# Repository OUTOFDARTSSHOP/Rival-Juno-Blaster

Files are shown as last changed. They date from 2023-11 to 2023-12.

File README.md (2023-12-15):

# Juno

Juno is the successor to Jupiter with increased FPS, improved features, and open source nature.
This blaster contains the new OOD Photons and custom-made Rival wheels that fit standard shell profiles.

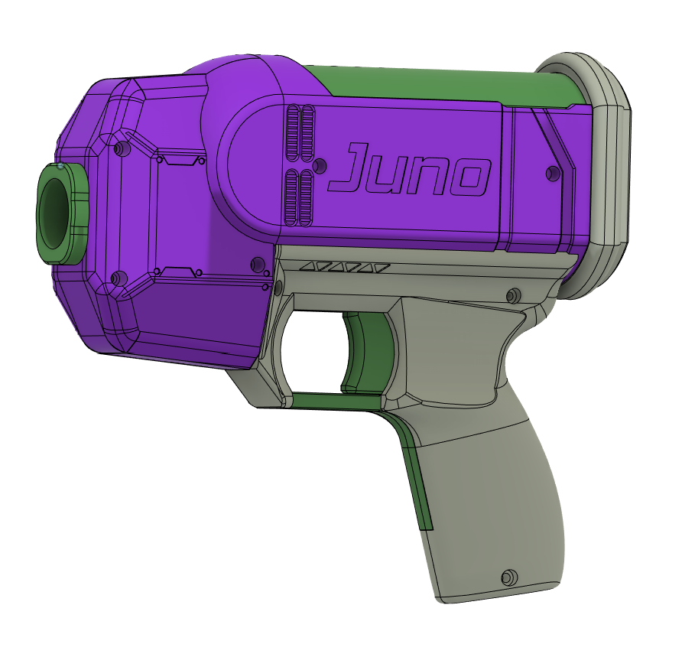
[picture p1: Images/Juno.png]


<details>
<summary> Changelog </summary>

- Changelog: 12-04-2023: v5.1 parts updated.
  -   N20 casing increased layers
  -   Cage shifted to accommodate the n20 case changes
  -   The chamfer on the pusher wheel is reduced to prevent slipping too far onto the shaft
  -   Added more plastic to the inner handle so the parts aren't just held by the pegs
- Changelog: 12-07-2023: v5.2 handle updates. 
  - Trigger trimmed in the right and left direction to help with sticking
  - A small chamfer was added near the trigger opening so seams didn't cause sticking.
- Changelog: 12-14-2023: v5.3 alternatives and clear instructions
  - Cage updated to include instructions on polarity and direction of motors
  - Add 2 more pusher wheel for looser fit
  - Update manual based on issue 1 and how the nozzle works. 

</details>

## Licensing

If you want to print and sell this item, please contact outofdarts@gmail.com.

<br />This work is licensed under a <a rel="license" href="http://creativecommons.org/licenses/by-nc-sa/4.0/">Creative Commons Attribution-NonCommercial-ShareAlike 4.0 International License</a>.

## Description

* Files can be found in two ways. The major file version can be found zipped together here. The latest release and any beta files can be on this GitHub.

* If you bought the hardware kit, it comes with two versions. The standard hardware contains all hardware for Juno and extra hardware for the Picatinny rails. Holdster Hardware replaces the M3 brass inserts with M5 and holdster magnets. Though not pictured, the installation process is the same. Only the Mag-Battery file needs to be changed.

* The battery is not included with the hardware kit. Most OOD batteries will fit in the large battery tray.

## Reviews

* Waiting for them to come in

### Hardware notes:

Hardware listing:
3D Printed + Hardware listing:
Fully assembled listing:

## Assembly

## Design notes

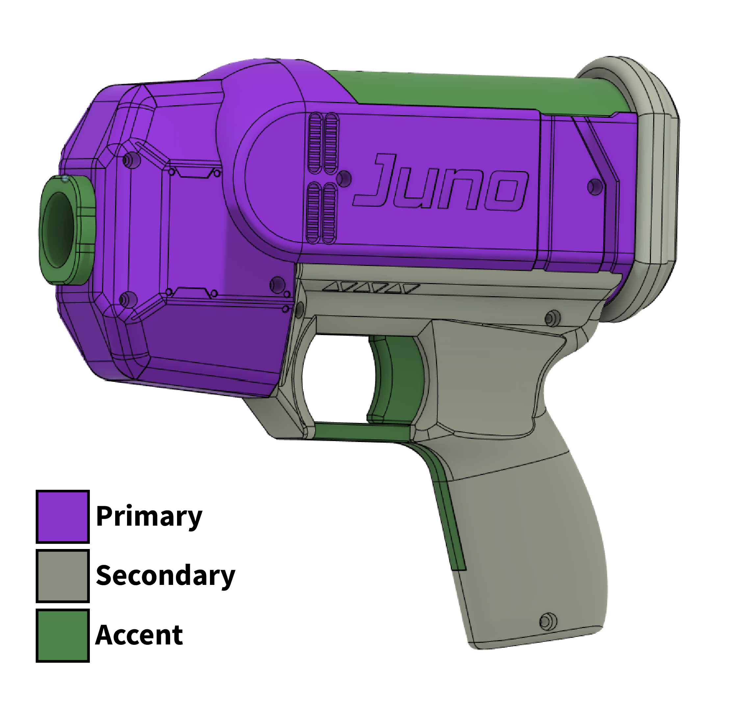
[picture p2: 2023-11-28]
Images/Juno-Colored.png

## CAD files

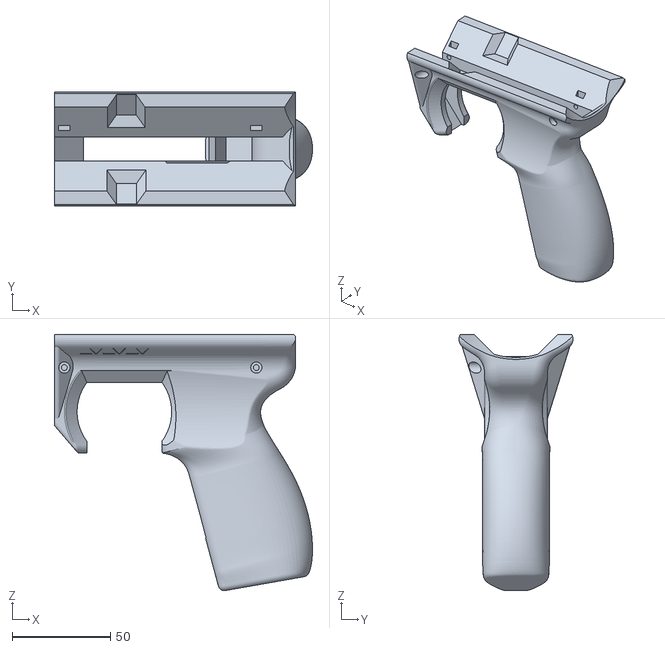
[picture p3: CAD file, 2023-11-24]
Juno v5/Archieve/Juno-HandleOuter_V5.stl
131.0 x 57.9 x 130.2

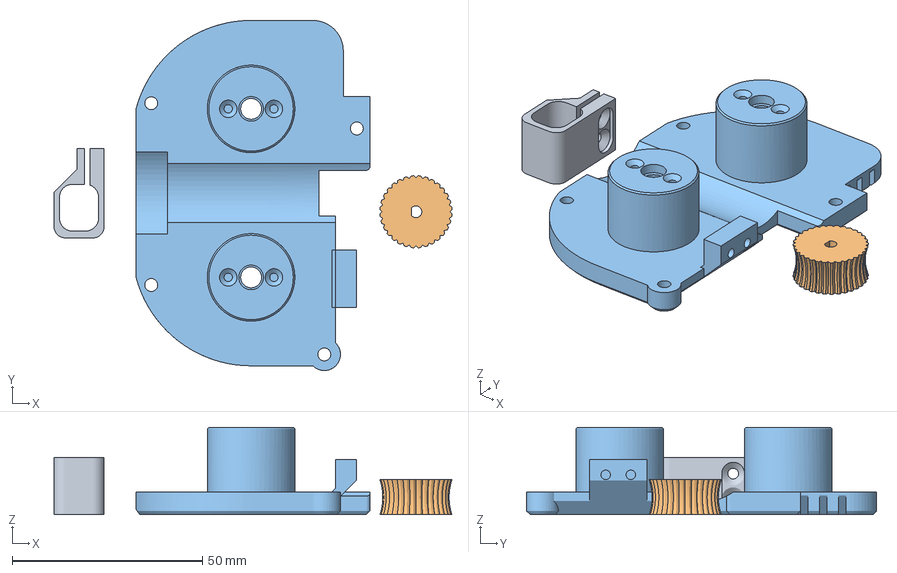
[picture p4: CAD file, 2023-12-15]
Juno v5/Juno-Misc_V5.3.3mf
104.6 x 92.0 x 23.0 mm
Juno-Pusher Casing_V5.1.stl
Juno-Pusher_V5.1.stl
Juno-Cage_V5.2.stl

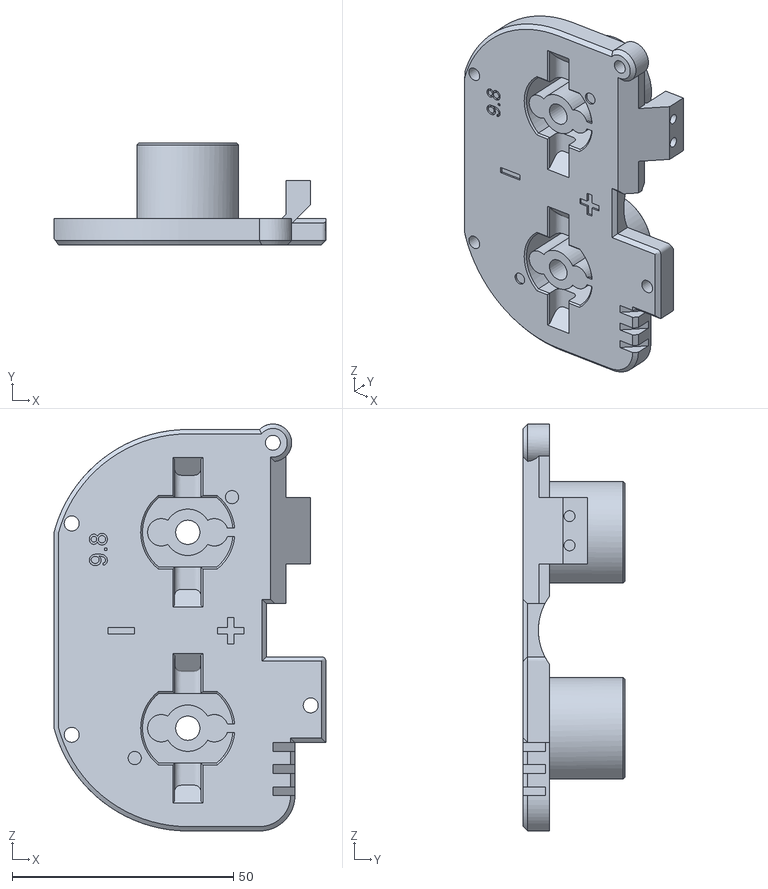
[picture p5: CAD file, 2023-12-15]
Juno v5/STLs/Front/Juno-Cage_V5.3.stl
61.5 x 23.0 x 92.0

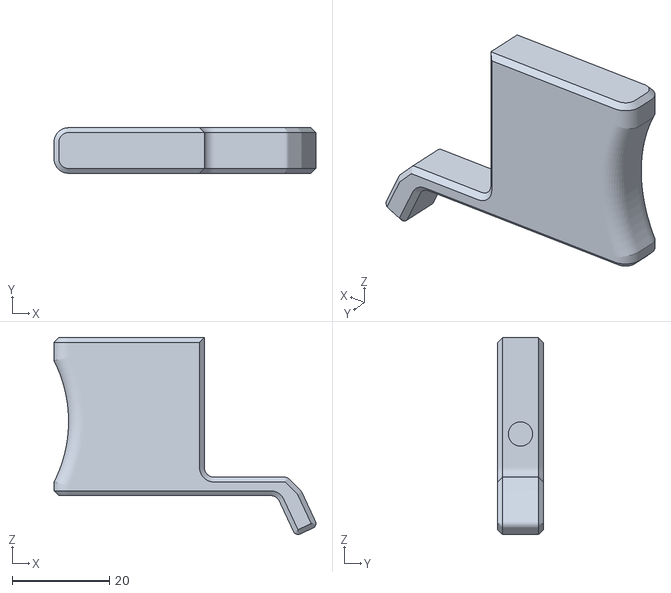
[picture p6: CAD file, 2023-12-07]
Juno v5/STLs/Handle/Juno-Trigger_V5.2.stl
54.0 x 9.40 x 40.6

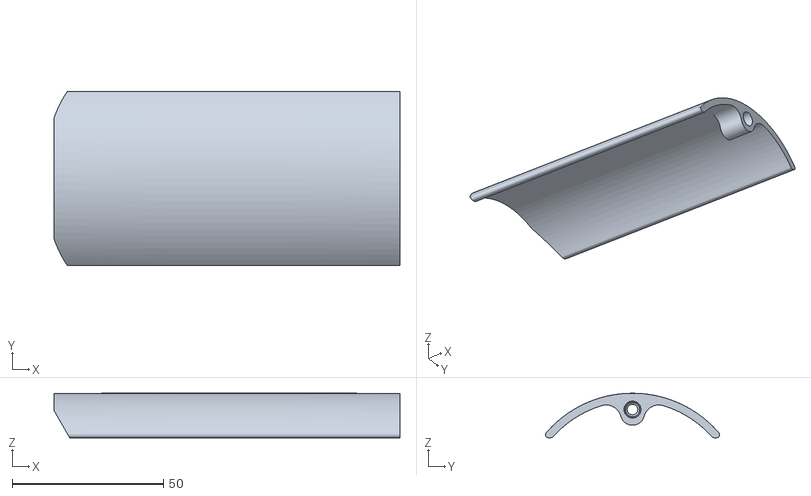
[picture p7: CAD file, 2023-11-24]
Juno v5/STLs/Mag-Battery/Juno-Cover_V5.stl
114.4 x 57.6 x 14.7

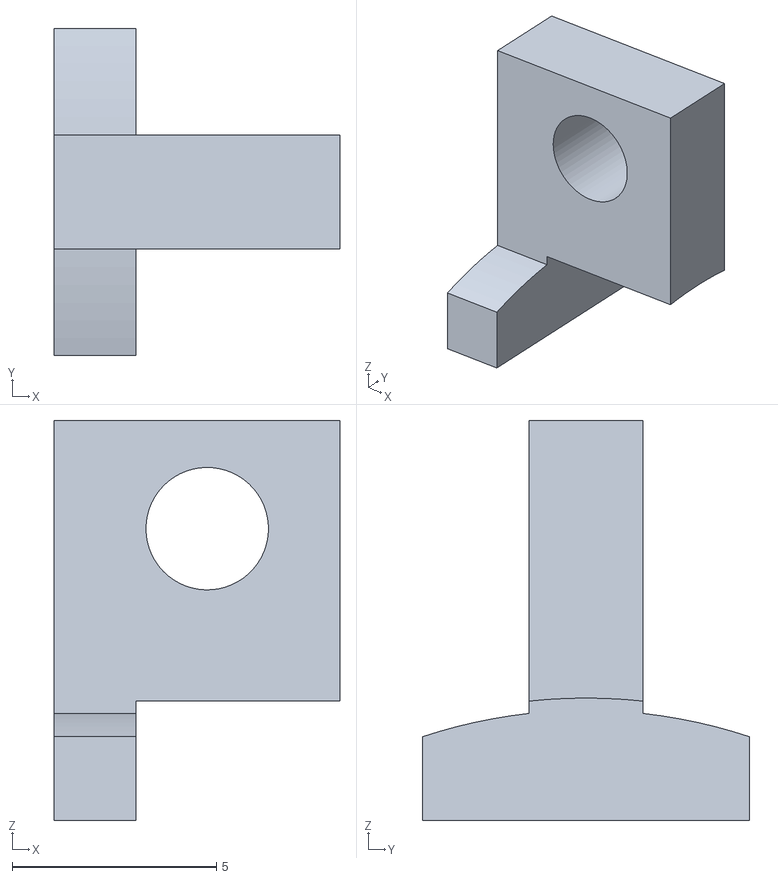
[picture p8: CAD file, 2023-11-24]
Juno v5/STLs/Nozzle/Juno-Thumb_V5.stl
7.00 x 8.00 x 9.80

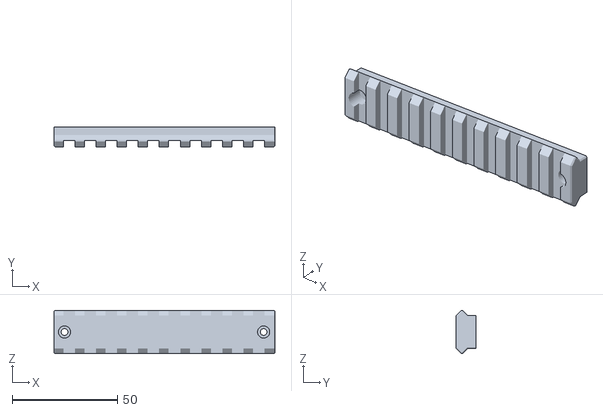
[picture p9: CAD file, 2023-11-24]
Juno v5/STLs/Optional/Juno-Rail_V5.stl
105.0 x 9.32 x 20.5

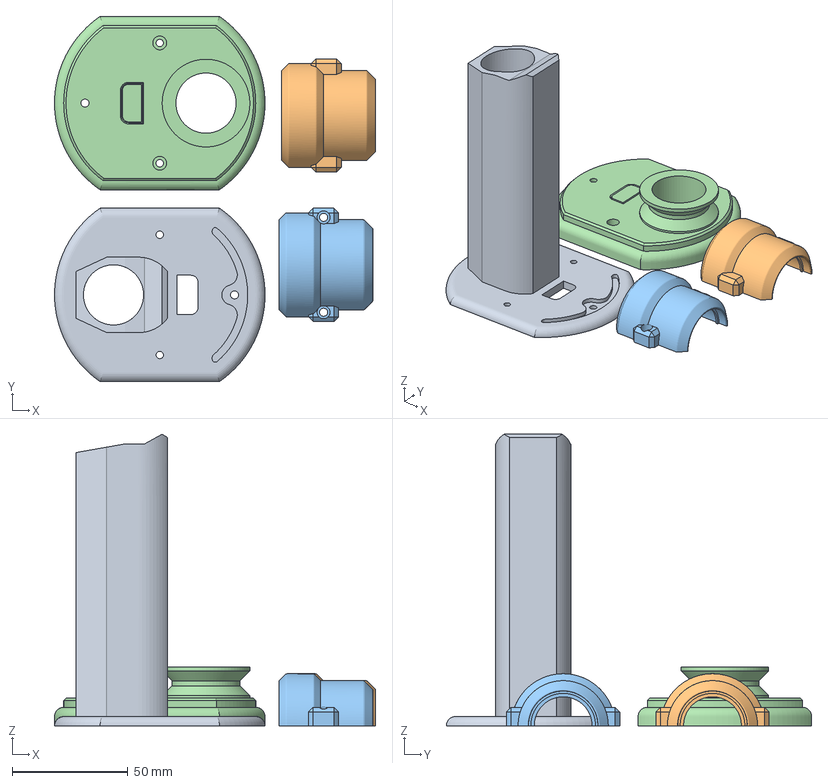
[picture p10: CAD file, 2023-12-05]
PPAdapter v2/PP-Adapter_V2.1.3mf
138.7 x 157.9 x 126.0 mm
BackPlate.stl_1
PP-Adapter v1.stl_1
PP-Adapter v1.stl_2
BackPlate.stl

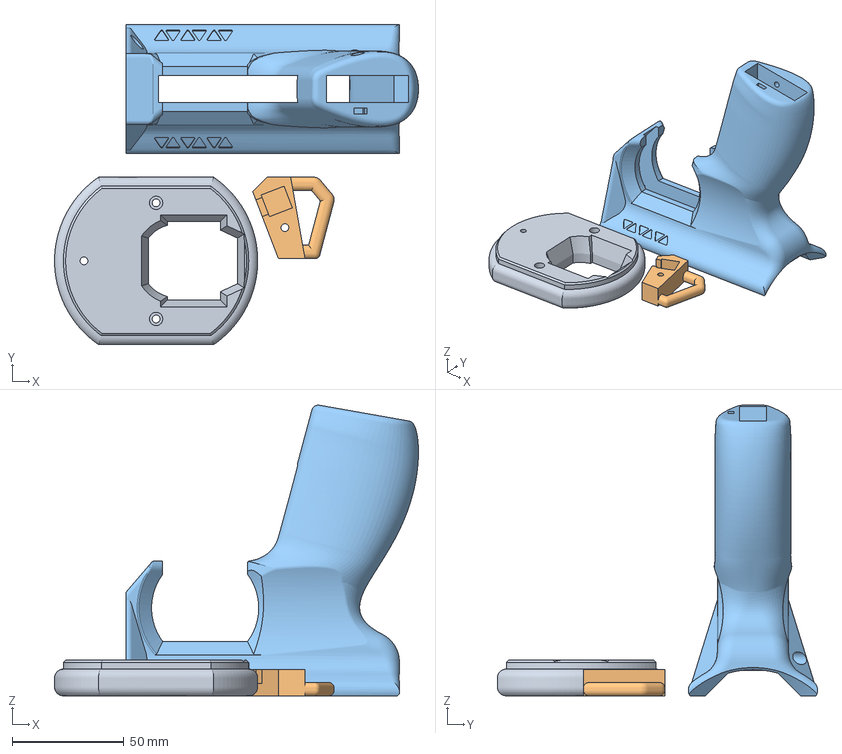
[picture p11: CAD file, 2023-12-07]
Juno v5/Juno-Secondary_V5.1.3mf
163.0 x 143.4 x 130.2 mm
f85b52f7-413b-456e-a1ac-1456022f8551.stl_23
Juno-SlingPoint.stl
Juno-HandleOuter_V5.2.stl

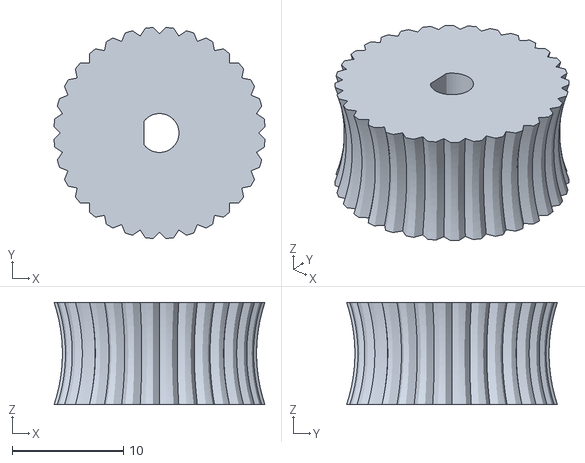
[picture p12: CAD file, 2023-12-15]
Juno v5/STLs/Front/Juno-Pusher-VeryLoose_V5.3.stl
19.0 x 19.0 x 9.20

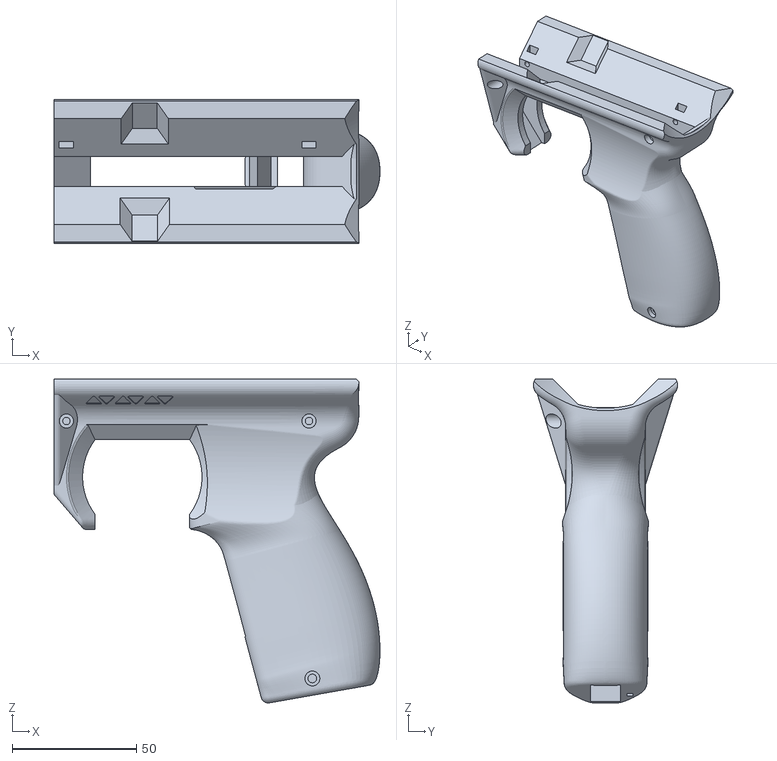
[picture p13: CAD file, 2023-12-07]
Juno v5/STLs/Handle/Juno-HandleOuter_V5.2.stl
131.0 x 57.9 x 130.2

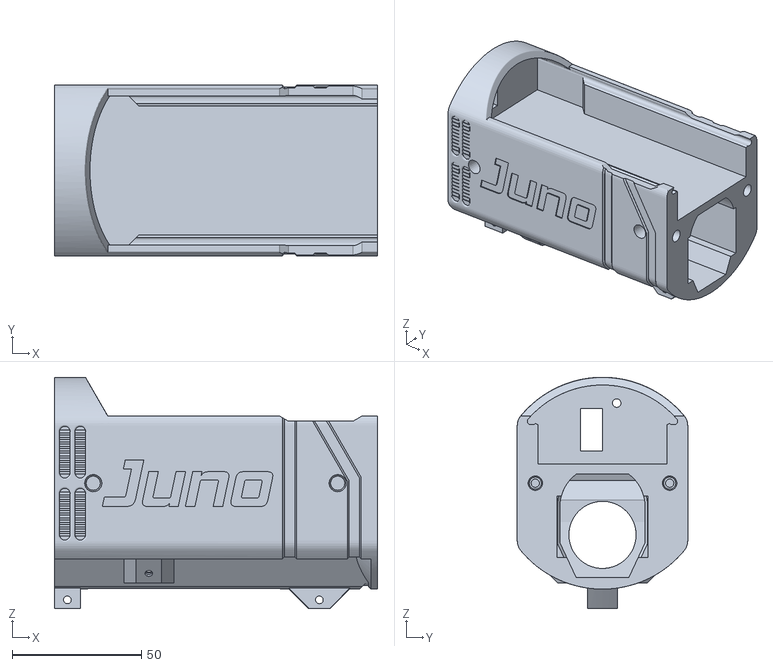
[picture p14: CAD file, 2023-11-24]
Juno v5/STLs/Mag-Battery/Juno-Mag-Battery-M5-Brass_V5.stl
125.0 x 66.0 x 89.6

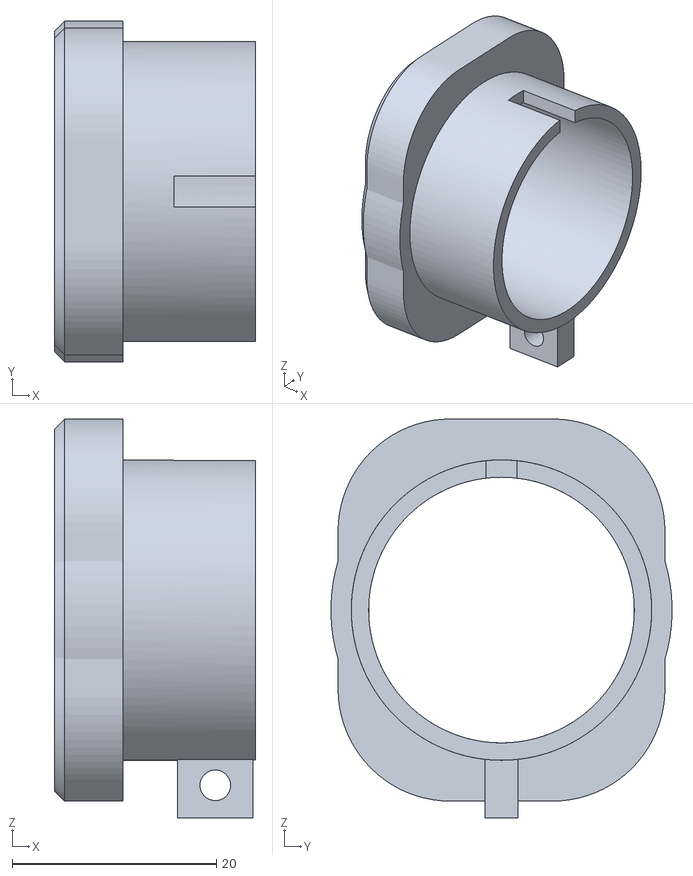
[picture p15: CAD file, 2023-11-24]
Juno v5/STLs/Nozzle/Juno-Nozzle_V5.stl
19.7 x 33.4 x 39.1

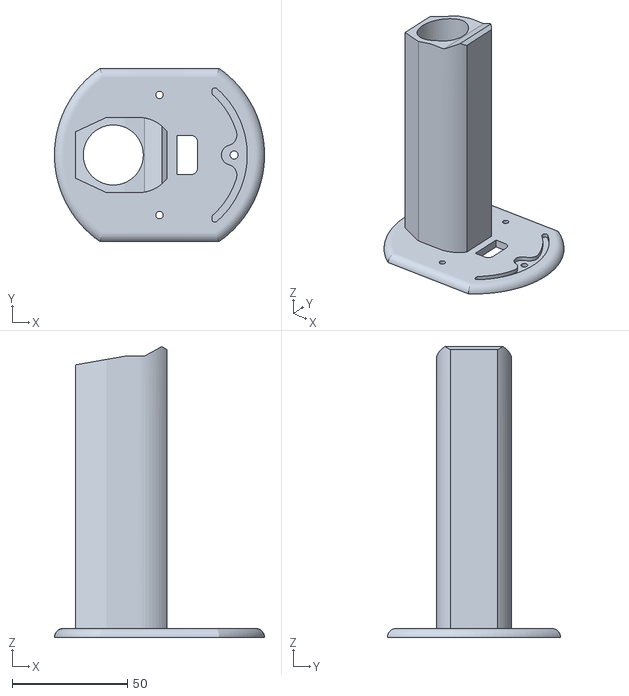
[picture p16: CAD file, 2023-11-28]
PPAdapter v2/PPAdapter-Insert_V2.stl
91.0 x 75.0 x 126.0

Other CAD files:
Juno v5/Archieve/Juno-Cage_V5.stl
Juno v5/Archieve/Juno-Misc_V5.3mf
Juno v5/Juno-Accent_V5.2.3mf
Juno v5/STLs/Front/Juno-Pusher-Loose_V5.3.stl
Juno v5/Archieve/Juno-Accent_V5.3mf
Juno v5/Archieve/Juno-HandleInner_V5.stl
Juno v5/Archieve/Juno-Pusher Casing_V5.stl
Juno v5/Archieve/Juno-Pusher_V5.stl
Juno v5/Archieve/Juno-Trigger_V5.stl
Juno v5/Juno-Accent-BatteryTray_V5.3mf
Juno v5/Juno-Primary-Mag-Battery_V5.3mf
Juno v5/Juno-Primary_V5.3mf
Juno v5/STLs/Front/Juno-Bottom Center_V5.stl
Juno v5/STLs/Front/Juno-Cage_V5.1.stl
Juno v5/STLs/Front/Juno-Left Plate_V5.stl
Juno v5/STLs/Front/Juno-Pusher Casing_V5.1.stl
Juno v5/STLs/Front/Juno-Pusher_V5.1.stl
Juno v5/STLs/Front/Juno-RightPlate_V5.stl
Juno v5/STLs/Front/Juno-Top Center_V5.stl
Juno v5/STLs/Handle/Juno-HandleInner_V5.1.stl
Juno v5/STLs/Handle/Juno-Juno'sFury_V5.stl
Juno v5/STLs/Handle/Juno-SlingPoint_V5.stl
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

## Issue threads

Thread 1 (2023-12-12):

Juno Nozzle V5

phoem, 2023-12-12:
Hey, The juno nozzle v5 either is not the latest version (only has 1 screw) or the directions need to be updated (shows a two screw version).  Not critical just feels like it was changed to add a two screw version but that may not have been uploaded yet.  Btw love the project and love the directions and the updates.  Thank you for all your hard work.

Turokhunter, 2023-12-12:
It’s both. Nozzle is held by one screw the other screw holds the hop up tab. It was designed so people can pick different hop up tabs depending on motors used.  The manual needs to be updated to show that. If you look at the 3rd print orientation image other manual you can see the tiny hopup between the trigger and rails. You can also gain slightly better performance if it’s printed TPU. All things that aren’t mentioned in the manual.

Thank you for pointing out that something was wrong. I can’t tell how hard it’s to catch all these tiny mistakes. I appreciate you taking the time to reach out.

phoem, 2023-12-13:
No problem, trust me I know I do software programming for a living, its impossible to find everything then combine that with having documentation you are maintaining too, it can't be easy.  Thanks for taking the time to explain what I wasn't seeing.

phoem, 2023-12-13:
Btw I am happy to help test anything before you release to main,whatever I can do to help

Turokhunter, 2023-12-14:
I appreciate the offer. In the other issue, I posted two pusher wheels you can try to fit off. I also do software development for a living. Once we get those tested, I will update the manual and the STL files.

Thanks for the help.

Turokhunter, 2023-12-15:
Updated in 5.3

Closed 2023-12-15.

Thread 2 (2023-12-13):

N20 pusher wheel doesn't fit

phoem, 2023-12-13:
I have tried printing both v5 and v5.1 of the pusher wheel and I can't get it to fit on the n20.  I have tried reaming out the hole but then it ends up too loose.  Printing on an X1C that is tuned and accurate.  I suspect this piece may need a few different versions or setting's depending on the printers accuracy but everything else in the build fits like a glove.  Thanks again for your hard work.

Turokhunter, 2023-12-14:
I expected this to happen. Give these two a try and let me know: https://www.dropbox.com/scl/fi/wcts8ksx3dfdsa4wa2cmc/Juno-Pusher-Loose_V5.2.stl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
https://www.dropbox.com/scl/fi/cj68pm7o5jzgaby5kloid/Juno-Pusher-VeryLoose_V5.2.stl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

KookyMawnster, 2023-12-14:
V5.1 worked for me Ender 2 Pro "hole horizontal expansion" = 0.1mm

phoem, 2023-12-14:
The loose version fits great, slides right on.  Very loose still fits of course but slides right off.

Thanks for the help.  Let me know if you want me to send photos

Turokhunter, 2023-12-15:
New files can be found in 5.3 version.

Closed 2023-12-15.

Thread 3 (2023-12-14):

V5.1 Inner handle cosmetic layer shift?

KookyMawnster, 2023-12-14:
Hi.  Printed V5 of inner handle at first, then saw V5.1 so printed that.  There seems to be a slight offset in the layers in V5.1 that was not there in V5.  It is apparent on the right side of the trigger guard, and IMO is cosmetic.  I printed 2 copies in different rotations and the layer shift is in both.

Turokhunter, 2023-12-14:
Can you post an image so I can see what is happening? 5.1 change was to make it a bit thinner to slide in.

KookyMawnster, 2023-12-15:
Hi Tarik,

V5 is in back, V5.1 in front. It is very subtle.

Love your design! I am printing it in black and yellow and call it Juno "Stinger".

Regards,
Mark

Sent from Proton Mail mobile

-------- Original Message --------
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

KookyMawnster, 2023-12-15:
Sorry here is the picture of the InnerHandle. And some pictures of my completed Juno, which I call "Stinger."
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

Turokhunter, 2023-12-15:
Nice, I was wondering if someone would take advantage of the center area and change up the color.  Is the layer shift on the same side as the flat plate? like it is on the Z-height location?

KookyMawnster, 2023-12-15:
If I understand your question, I will answer yes.  I have not tried to import the .stl into a CAD program, but it "appears" as though the base object upon which the other elements are built upon had shifted down in the Y-direction as oriented on the plate.  Although the "shift" is only apparent in the trigger guard area and NOT the top-most edge of the InnerHandle.

KookyMawnster, 2023-12-15:
After looking more closely, another way of describing this is that it appears the oval "hole" of the trigger guard area was made slightly bigger in V5.1

Turokhunter, 2023-12-15:
When you printed it, did you use a 3mf file or import the STL file directly into a slicer?
I'm not seeing anything in the STL viewer.
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

What about when you look at through the slicer? I'm not seeing it in mine, but I'm interested to know if you are.

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

KookyMawnster, 2023-12-15:
Oh hey I'm seeing it in the slicer......
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
It's printer settings then.  I went back to default standard and I don't see that anomaly anymore.  I even modified the settings from default again to what I thought I did and I'm not replicating it anymore.  I'm at a loss what setting(s) is causing that.

KookyMawnster, 2023-12-15:
Found it.  Horizontal Hole Expansion = 0.1 mm is causing it - setting back to 0 mm eliminates it.

Turokhunter, 2023-12-15:
OHH, so the slicer thinks the trigger guard is one large hole. That is very interesting. Good Luck with the wiring!

Closed 2023-12-15.

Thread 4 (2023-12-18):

Hop-up tab

KookyMawnster, 2023-12-18:
Hi!  Finally finished my build.  Even wired it to do a 3-shot burst 8).
Would it be possible to make a couple hop up tabs to try that are a little bigger? Definitely in the horizonal dimension, but also a bit in the vertical dimension?  I have a Perses and the hop-up tab is quite substantial.  From 25 feet away all shots hit a 2x3 door window.  The Juno at times shanks balls like a drunk golfer - i feel the balls are sometimes catching more of the corner of the hop-up tab (using TPU BTW)....Please and thanks in advance.

Turokhunter, 2023-12-18:
I made an adjustable hop-up, where you can change the Depth with m3 screw. Do you have m3 x 8mm screw?

KookyMawnster, 2023-12-19:
Yes I will try that.

Turokhunter, 2023-12-20:
Here are the 8mm and 10mm(this screw came in the hardware kit) for the side versions. Give this a try, and let me know if it helps or worsens it. These are very much experimental designs.

8mm m3: https://www.dropbox.com/scl/fi/k85dqsc0absgw8wncjm47/Nozzle-Adjustable-v1.3mf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
10mm m3: https://www.dropbox.com/scl/fi/r2ufx46qfqeuanzkb84up/Nozzle-Adjustable-10mm-v1.3mf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

phoem, 2023-12-27:
In my tests so far I am not running into this issue.  Will do further testing tomorrow when I can see better.  How did you wire the 3 shot burst using an arduino?

KookyMawnster, 2023-12-27:
Hi,
No it's the analog way with a capacitor. It's not perfect. Sorry holiday's always a busy time I drew a wiring diagram just have to find time to post it.
I know BBC micro:bit well if done digitally I would put an IR break beam counter in the barrel/nozzle and control the n20 motor with the micro:bit, cutting it off when the IR beam counts 3

Sent from Proton Mail mobile

-------- Original Message --------
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

phoem, 2023-12-27:
No problem, please share when you can.  Are you cutting all the motors off at the 3rd shot or just the n20? Could it be they are getting cut off a hair early and thats affecting tbe trajectory and power of your 3rd ball? I am assuming a lot here I know.  I will do some tests when its sunny today, don't have a large enough area inside unless I want to watch  them ping pong off 3 walls :)

KookyMawnster, 2023-12-28:
I think it's the alignment of the wheels but it's seemingly solved itself. Have yet to try Tarik's adjustable hop up tabs.
Here is the wiring diagram it just shows the circuit to the pusher motor. I ended up using a 4700 mF capacitor.

-------- Original Message --------
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

KookyMawnster, 2023-12-28:
Sorry not sure if the wiring diagram showed up
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

Turokhunter, 2023-12-28:
If it’s working I wouldn’t touch it. The adjustable hop-up might sound great but there is a reason I didn’t include at first. It’s way too easy to set the hopup wrong and either tank your balls or end up shooting the sky.

KookyMawnster, 2023-12-28:
Ya I'm find the hopup tab in TPU work but they are tearing. I had printed one in PLA before finding out they should be in TPU....wicked hopup.  I filed the leading edge down a bit which greatly reduced the hopuo so when I have time I will try to file it down more.
On another note, I find the size of the pusher fine for Rival rounds, but not for the slightly larger and denser dart zone rounds. These don't feed.  I ended up printing the loose pusher at 92% in the x and y dimensions.  Now the feeding is flawless.  It doesn't help that the magazine springs are quite weak to start with.

Turokhunter, 2023-12-28:
Yea, I received an email yesterday about the tpu tearing. I will have to investigate. In my build I have been mostly using Pla version and it works fine. Are you mostly using dart zone rounds? I wonder if they are the cause of the PLA version not doing the right hop up and  tearing of the tpu. If so, I might need to design separate parts or figure a more robust solution.

Hmm resizing the wheel will cause to feed slightly different. Let me know if affects aim. I try to do more investigation.

KookyMawnster, 2023-12-28:
You know Tarik I think your design is great. It is the nature of the beast printing with melted plastic, with different filament brands and printers, that there will be variances so I thought I would give you a big thanks for this project 👍  To me if people have to make adjustments it's because we are 3D printing not injection moulding or CNCing aluminum

phoem, 2023-12-30:
I ran quite a few tests and I am not seeing any issues with the shots so I think you are probably right it might be something related to your print tolerances. But it sounds like you fixed it so awesome.  Turok, The tpu hopper that came in the OOD kit hasn't worn or broken on me so maybe the person who has one that broke got a bad print, TPU can be finicky after all.  If mine breaks though I will let you know and just print  some more.  Have some TPU-95A High Flow I have been wanting to try out so maybe ill print a few backups just in case.  Love the gun! Thanks again

Turokhunter, 2023-12-31:
I can always thicken up the hopup, but it will lose some flexibility. Let's see if others are running into issues so we can nail down what is happening.

KookyMawnster, 2024-01-12:
Update - I filed the PLA hopup tab a little more and took a hair off the height.  Rounds fly a lot straighter now. Pretty much now a 45 degree bevel on the leading face of the hopup tab that faces towards the flywheels.

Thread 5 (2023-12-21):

Stuck screw help

phoem, 2023-12-21:
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

While putting that screw in it made it like 90pct there then got stuck (my guess is the square nut needs realigning) but i am having massive trouble getting the screw out. Its just spinning in place.  This isn't a problem with the build/files just hoping you have a suggestion to get it out as I have tried every trick I know. Appreciate any input from your experience thanks

Turokhunter, 2023-12-21:
If the screw is not stuck in the square nut and is free spinning. Press against one side of the walls, this will get the threads to bite into the plastic and should give you enough perches.  You can also hold it upside down, let gravity help you as well, but the wall trick usually does the trick.

phoem, 2023-12-21:
Thanks yea I tried upside down, leaning against the wall, prying it up at the same time.  About 30 minutes last night before I posted and another 30 minutes this morning.  No luck.  My neighbor comes by gives it a shot within 3 minutes he got it out doing the exact same thing. Lol.  It's like the pickle jar you can't open then your wife opens in 2 seconds after you loosened it up :). Appreciate the suggestions got it all set now  :)

phoem, 2023-12-21:
Oh and it was my stupidity not the nut sitting wrong. I thought all the remaining screws were 25mm but there were 25 and 30mm and I picked up a 30mm instead of a 25mm.

Turokhunter, 2023-12-21:
The issue you describe has happened so many times during testing, so I have developed quite a few methods to get a screw out.

The 30mm vs. 25mm was a last-minute change. I wanted them all to be 25mm, but we found that you need to set the front square/hex correctly to avoid not catching the nut or pushing it out of place. Then, you would have to take the entire front apart.

Let me know if you have the same issues as number 4, with a few balls veering off.

phoem, 2023-12-22:
Will do, I should be able to finish and test it today, I am using a tpu hopper I wonder if that will help

phoem, 2023-12-26:
So I am not sure whats wrong and I think this is a different issue than the other issue in here but everything revs up but the ball just sits there jt never catches on with the pusher wheel and never fires. Any suggestions

Turokhunter, 2023-12-26:
Check the directions of each of the wheels and the pusher. That is usually the issue.

phoem, 2023-12-26:
They all are spinning in the right direction but the pusher never seems to catch.  Here is the direction the motors are spinning:

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

phoem, 2023-12-26:
Oh and in case you wanted to see how she looks (I love protopasta and I know you guys do too).  I am pretty happy with the color combo

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

Turokhunter, 2023-12-26:
Lovely colors! I understand how your motors are spinning, but you have the arrow for the pusher going away from the wheels. I'm not sure if that is the representation or what.

Try these in order:
First, point the blaster down into the ground and place a single ball, with no magazine, into the chamber. Pull the trigger and see what happens.
If the blaster fires the ball, place a mag into the chamber next. Push against the back of the mag with your other hand and try to fire again.

Let me know the results.

phoem, 2023-12-26:
Thanks! I realize yea that arrow is pretty confusing, I was trying to show how the motor would look like it was spinning when looking at it from the same focal point as the picture.

The ball doesn't fire, apologies for showing off the kitchen sink but it was the best way I could take video and still get light to enter the chamber so you can sort of see the ball.

https://github.com/OUTOFDARTSSHOP/Rival-Juno-Blaster/assets/94163/ee9bc1bd-3c69-4ca3-9493-e3378df5aa2e

phoem, 2023-12-26:
On further inspection it is my pusher moving the wrong way you are right, my eyes were playing tricks on me the pusher wheel looks to be spinning forward but in fact it was spinning backwards.  I forget what that "eye sight trick" is called but going to switch it now. Thanks. Ill let you know how it goes

Turokhunter, 2023-12-27:
Awesome! I should have mentioned what it means if it failed each step. The first step, as you guessed, means the motor is spinning the wrong way. If holding the mag causes it to fire, that means the Ball dedents aren't installed correctly.

phoem, 2023-12-27:
Thanks again that was it now it works fantastically! Looking into that other issue for you now

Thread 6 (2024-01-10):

Ball Detents

nustherapy, 2024-01-10:
Greetings,

I am starting my Juno build and have printed the Juno-Mag-Battery-3m-Brass_V5.stl main body. When installing the ball detents there is no mention of using any glue or anything like that in the assembly guide however when putting them in place they fall out if the body is flipped upside down. Is it expected that they are friction fit, or should super glue or some other adhesive be used to hold them in?  For what it's worth this was printed on a standard Prusa MK3S, with the .20 layer profile, with 5 walls, and 25% infill.

I have inserted the hex nuts, and square nuts into the top and bottom center, and these are all snug tight fits.

Turokhunter, 2024-01-11:
Hey, Sorry for the delay; I've been sick. You can use a bit of super glue to hold them, but be careful not to get any glue on the ball or inside the ball dedent through the small hole on the bottom.

Yes, they are normally friction fit for me. I know Luke and the team glue their detents, and I bet when the video comes out, he will make that suggestion.

nustherapy, 2024-01-11:
Thanks so much for getting back to me on this and I hope you will be feeling well soon!

I do think this would be a good note to add to the documentation, which otherwise has been great!

It is a bit of a challenging location to manage superglue especially with the concerns of impacting the functionality of the detent itself. In other builds I've used 'poster putty' to holds springs in place mostly for ease of assembly, however I wonder if that may also be enough to work in this scenario as well.

Turokhunter, 2024-01-11:
I appreciate it. I will add it to the manual.

I'm not sure about poster putty. You only need to hold it in place while a mag is not installed. Maybe you can take advantage of the hole on the outside? Otherwise, to install with super glue, apply a very small amount on the outside casing before inserting it into the body. Then, with a paper towel, wipe up any glue that leaked out either hole.

nustherapy, 2024-01-11:
So I decided to give the poster putty a try, I rolled up a little ball of it and dropped it into the hole for the detent and then simply pressed the detent in. As I did that a bit of excess putty came out of the hole which I just flattened and removed. This seemed to hold really well (which isn't that surprising as when I use this on springs is always holds them well)! I was able to hold the part upside down and knock it around a bit with my hand and the detents held securely in place.  I then tested with a mag, inserting/removing a number of times and again trying to knock them out of place and still held in place.  Now time will tell how environmental conditions impact this or if the putty will deteriorate but for me I'm willing to take the risk.  I can certainly understand where you may not advise this in the official documentation without fully testing, especially as it's known that super glue will just work but just thought I would share my experience.

As a side note, for what it's worth I'm so happy this design/build was made available for hobbyists to print on their own, once I saw the files for this would be available to print myself, I made sure to get myself a hardware kit in short order!

Turokhunter, 2024-01-11:
It's great that it worked out. Keep me updated on how it fairs in use.

I am really happy to hear that. With A1 and other more consumer-friendly printers, I think this is the general direction that all 3d printing is going.  I don't think we will be doing this with every design.  It will depend on whether the designer wants to release their files and if it makes sense to do so.  The next one I'm looking into is Herja version 1.2. I think that Blaster would work well for the community to mess with and there few improvements we can make (it might change the shape).

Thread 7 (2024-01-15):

Documentation Suggestion

nustherapy, 2024-01-15:
This is not really an issue but a suggestion on the documentation. I hope this is an acceptable place to share this feedback.

I think the documentation would benefit from a electrical schematic drawing with the terminals on switches, and motors properly labeled.  With that said I think the current drawing should still remain, as it's helpful but at the same time a more accurate/standard schematic would also provides a bit more confidence I think in the build.

Turokhunter, 2024-01-16:
Thanks for the feedback. Hopefully, Luke will find some time soon to record a video, and I believe that should help quite a bit.

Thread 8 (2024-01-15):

Sugggestion : Flywheel Allignment

nustherapy, 2024-01-15:
I would love to see a flywheel alignment shim/spacer/jig whatever you want to call it to get the flywheels setup properly. I've found this very useful on other builds like the Hummingbird, and the Flycore fileset also comes with several different shim/spacers as there is alot more variety there. But I do think a spacer for the 'standard' hardware kit for the Juno as a printable option would be a great addition to the fileset.

Turokhunter, 2024-01-16:
I believe for Juno, you can push the wheels all the way down. There is a small ridge I added to the wheels to prevent them from bottoming out.

Or maybe am I missing something? let me know!

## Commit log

2023-11-24 First commit.
    [Juno-Accent-BatteryTray.3mf, Juno-Accent.3mf, Juno-Back Cap.stl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]
2023-11-28 Added the proton pack adapter.
    [PP-Adapter.3mf, PPAdapter-Backplate.stl, PPAdapter-Insert.stl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]
2023-11-28 Updated the names of the file.
    [Juno-Accent-BatteryTray_V5.3mf, Juno-Accent_V5.3mf, Juno-Back Cap_V5.stl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]
2023-12-05 5.1 Update.
    [Juno-Accent_V5.1.3mf, Juno-Accent_V5.3mf, Juno-Cage_V5.1.stl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]
2023-12-07 More updates.
    [Juno-Accent_V5.1.3mf, Juno-Accent_V5.2.3mf, Juno-HandleOuter_V5.2.stl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]
2023-12-15 Update Juno v5.3, check changelogs.
    [Juno-Cage_V5.3.stl, Juno-Misc_V5.1.3mf, Juno-Misc_V5.3.3mf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]
